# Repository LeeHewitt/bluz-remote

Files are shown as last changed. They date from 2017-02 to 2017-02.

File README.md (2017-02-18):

<p align="center" >
Bluz
</p>

Bluz Remote Files
==========
Bluz is a Development Kit (DK) that implements the Wiring language and talks to the [Particle](https://www.particle.io/) cloud through Bluetooth Low Energy. It can be accessed through a REST API and programmed from a Web IDE.

The Bluz Remote is a device that can be used to control many Particle projects. It provides a simple layout for buttons thaqt publish events, the events can then be subscribed to by various Particle services for control.

Example projects to control include:
* Robotic projects 
* IR Transmitters to control TV's, DVD's, etc
* RF Transmitters to control light switches, outlets, etc

Project Page: https://www.hackster.io/eely22/universe-remote-5830e2

###PCB 
The PCB is available on OSH Park:

 

##Sections
<b>BOM</b>: Current Bill of Materials for the remote.

<b>HW Design</b>: Schematics, board layouts, and other design files.

<b>3D Files</b>: 3D Models of the PCBA and Case

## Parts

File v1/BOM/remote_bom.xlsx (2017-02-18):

Part(s) | Package | Value | Description | Qty | Manufacturer | Mfg. Part Number | Data Sheet | Notes
Q1 | SOT323 |  | P-Channel MOSFET for reverse polarity protection | 1 | On | NTS2101PT1G | data (http://www.onsemi.com/pub_link/Collateral/NTS2101P-D.PDF)
S1 | Thru |  | DPDT Power Switch | 1 | E-Switch | EG1270 | data (https://www.e-switch.com/system/asset/product_line/data_sheet/119/EG.pdf)
C1 | 0603 | 0.1uF | 0603 Package | 1 |  | GRM188R71C104KA01D | data (http://search.murata.co.jp/Ceramy/image/img/A01X/partnumbering_e_01.pdf)
BAT1 | SMD | 20mm | Battery holder for CR2032 | 1 | Linx | BAT-HLD-001 | data (https://www.linxtechnologies.com/resources/diagrams/bat-hld-001.pdf)
JP2, JP3 | Thru |  | 0.1" 12-pin stackable female header | 2 |  | 68000-412HLF | data (http://www.digikey.com/product-detail/en/68000-412HLF/609-3266-ND/1878525)
S2-S9 | SMD |  | Tactile Switch | 8 | Alps | SKHUALE010 | data (http://www.alps.com/products/WebObjects/catalog.woa/E/HTML/Tact/SurfaceMount/SKHU/SKHUALE010.html)

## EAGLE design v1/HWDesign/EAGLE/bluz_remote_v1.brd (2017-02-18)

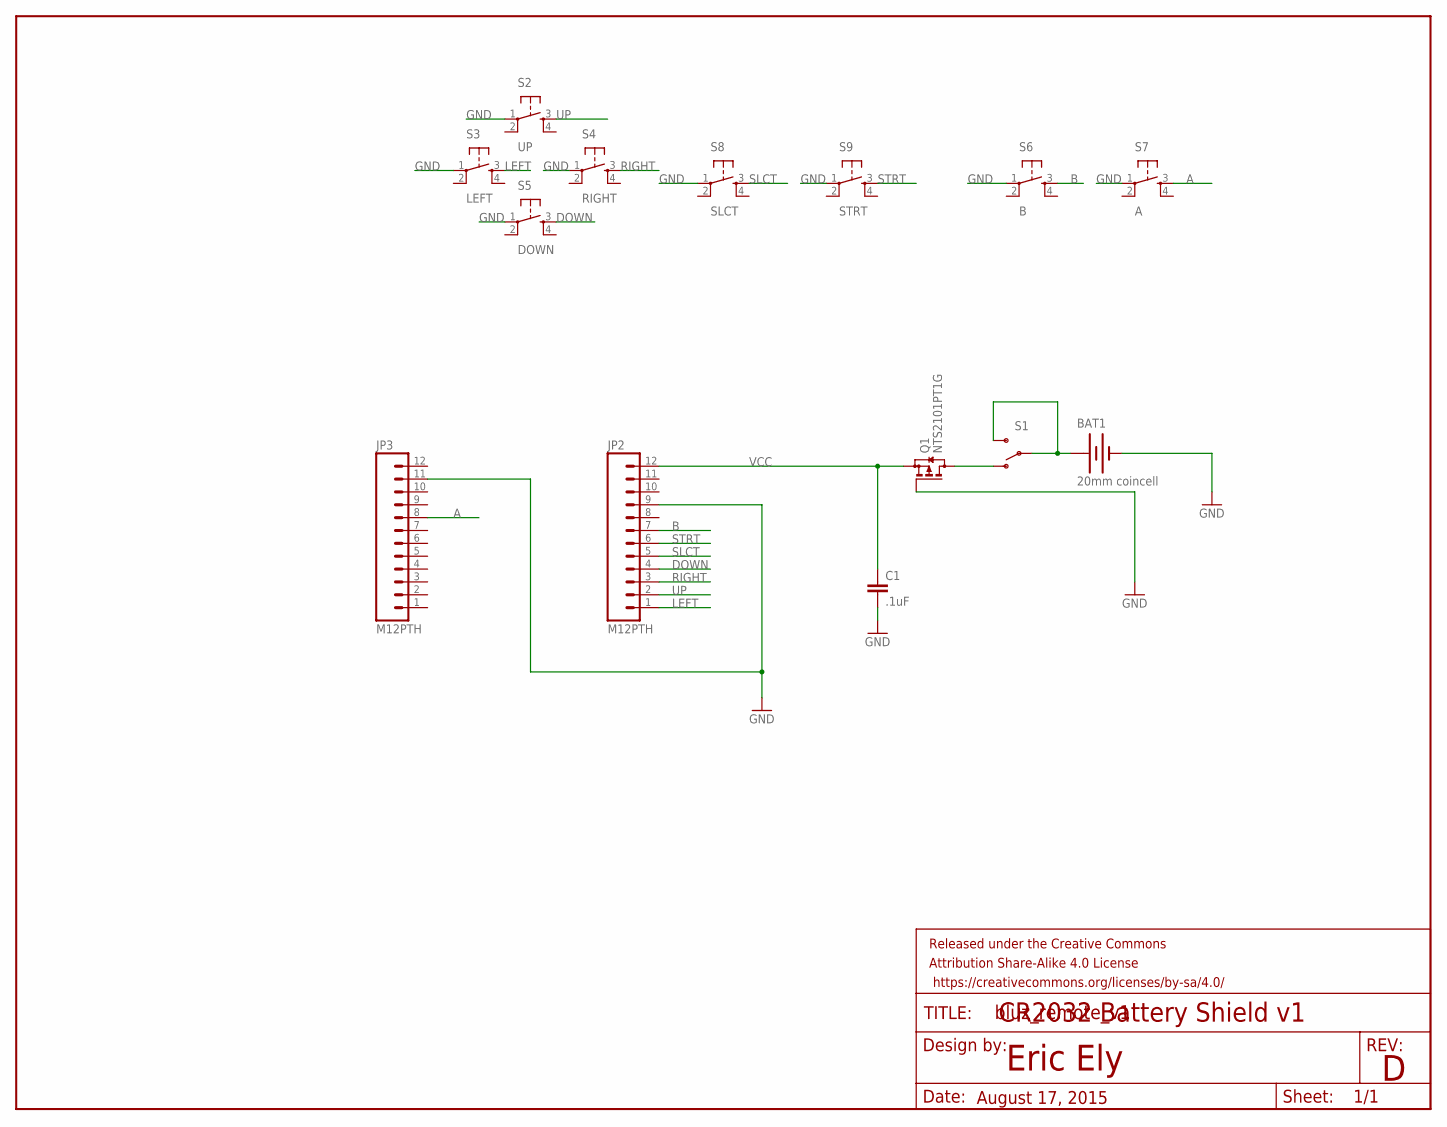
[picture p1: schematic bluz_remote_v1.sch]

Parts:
BAT1: 20mm coincell; BATTCON_20MM_4LEGS
C1: .1uF; 0603-CAP
FRAME1: FRAME-LETTER; CREATIVE_COMMONS
JP2, JP3: M12PTH; 1X12
Q1: NTS2101PT1G; SOT323
S1: SWITCH-SPDTKIT; SWITCH-SPDT_KIT
S2: UP; TACTILE_SWITCH_SMD
S3: LEFT; TACTILE_SWITCH_SMD
S4: RIGHT; TACTILE_SWITCH_SMD
S5: DOWN; TACTILE_SWITCH_SMD
S6: B; TACTILE_SWITCH_SMD
S7: A; TACTILE_SWITCH_SMD
S8: SLCT; TACTILE_SWITCH_SMD
S9: STRT; TACTILE_SWITCH_SMD

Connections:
A: JP3.8, S7.3
B: JP2.7, S6.3
DOWN: JP2.4, S5.3
GND: BAT1.2 (-), C1.2, JP2.9, JP3.11, Q1.1 (G), S2.1, S3.1, S4.1, S5.1, S6.1, S7.1, S8.1, S9.1
LEFT: JP2.1, S3.3
unnamed: BAT1.1 (+), S1.2, S1.3 (S)
unnamed: Q1.3 (D), S1.1 (O)
RIGHT: JP2.3, S4.3
SLCT: JP2.5, S8.3
STRT: JP2.6, S9.3
UP: JP2.2, S2.3
VCC: C1.1, JP2.12, Q1.2 (S)

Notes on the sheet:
Eric Ely
August 17, 2015
CR2032 Battery Shield v1

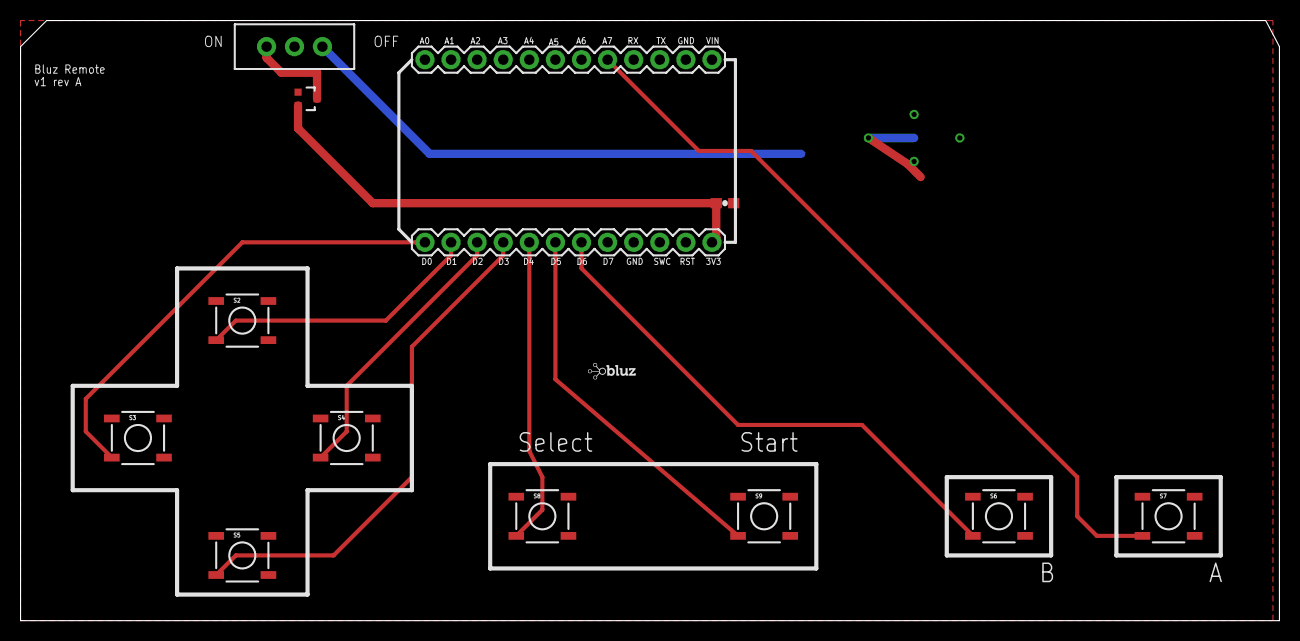
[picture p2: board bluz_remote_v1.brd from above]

Board: 2 copper layers, 122.6 x 58.4 mm, 16 parts (1 on the bottom side), 12 nets.

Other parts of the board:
U$1: BLUZE_LOGO_LOW_RES

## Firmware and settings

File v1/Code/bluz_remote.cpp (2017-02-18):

#define UP D1
#define LEFT D0
#define DOWN D3
#define RIGHT D2
#define START D5
#define SELECT D4
#define B D6
#define A A7
#define BUTTON_COUNT 8

#define DEBOUNCE_TIMEOUT 250
#define INACTIVE_TIMEOUT 3600000

BLE_ADV_NAME("REMOTE");

bool send_event = false;
long debounce = 0;
long time_since_last_activity = 0;
int last_button_index = 0;

typedef struct button_commands {
    int button;
    String command;
    
} button_commands;

button_commands buttons[BUTTON_COUNT]={
    {UP, "UP"},
    {LEFT, "LEFT"},
    {DOWN, "DOWN" },
    {RIGHT, "RIGHT" },
    {START, "START" },
    {SELECT, "SELECT" },
    {B, "B" },
    {A, "A" }
};

void button_pressed()
{
    for (int i = 0; i < BUTTON_COUNT; i++) {
        if (digitalRead(buttons[i].button) == LOW && millis() - debounce >  DEBOUNCE_TIMEOUT) {
            send_event = true;
            debounce = millis();
            time_since_last_activity = millis();
            last_button_index = i;
        }
    }
}


void setup() {
    Wire.end();
    
    //reduce tx power to reduce battery consumption
    BLE.setTxPower(-8);
    
    // setup each button
    for (int i = 0; i < BUTTON_COUNT; i++) {
        pinMode(buttons[i].button, INPUT_PULLUP);
    }
}

void loop() {
    System.sleep(SLEEP_MODE_CPU);
    
    for (int i = 0; i < BUTTON_COUNT; i++) {
        if (digitalRead(buttons[i].button) == LOW && millis() - debounce >  DEBOUNCE_TIMEOUT) {
            send_event = true;
            debounce = millis();
            time_since_last_activity = millis();
            // last_button_index = i;
            Particle.publish("Bluz Remote", buttons[i].command, PRIVATE);
        }
    }
    
    //if no one has pressed a button in a while, power off to save the battery
    if (millis() - time_since_last_activity > INACTIVE_TIMEOUT) {
        System.sleep(SLEEP_MODE_DEEP);
    }
}

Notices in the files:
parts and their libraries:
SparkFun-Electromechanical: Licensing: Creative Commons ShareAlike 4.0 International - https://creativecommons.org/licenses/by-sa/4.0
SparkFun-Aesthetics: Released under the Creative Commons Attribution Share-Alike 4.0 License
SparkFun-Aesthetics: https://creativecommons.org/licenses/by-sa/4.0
